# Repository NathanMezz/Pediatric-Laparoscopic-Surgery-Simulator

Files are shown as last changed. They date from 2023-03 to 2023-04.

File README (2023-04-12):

Repository for SYSC4907 Capstone Engineering Project "Pediatric Laparoscopic Surgery Simulator" at Carleton University (Fall 2022/Winter 2023)

Group Members:
Nathan Mezzomo
Miles Sutherland (Kilometers4444)
Titus Priscu

Main.py is the main program for running the project.

HSV.py is a supplmentary program from https://toptechboy.com/tracking-an-object-based-on-color-in-opencv/ which allows a user to
find an appropriate range of HSV values for specific colour detection. Modified to find pixel coordinates of centroids of objects.
Can be used for finding HSV ranges needed for ring task in Main.py.

Two Camera HSV.py is a modified version of HSV.py that implements the same functionality as HSV.py, but with two cameras to allow
for 3D object tracking. Attempting to combine two sets of 2D coordinates into one 3D coordinate set.

sensor_data.txt is where all the sensor data from the previous attempt is saved.
outpy.avi is the video recording of the previous attempt.
Warning_list.txt is the list of all warnings and their timestamps from the previous attempt.

Recommended Software:
- Anaconda (For python 3.9 install and libraries)
- PyCharm Community (python IDE)
- Arduino IDE

- The MPU6050's interfacing code was based on the Arduino library "MPU6050_tockn": https://github.com/tockn/MPU6050_tockn noteable changes were with respect to the addressing since using a second MPU6050 requires the change in address "0x68" to "0x69" when using the AD0 pin.  
- The PMW3389's interfacing code was based on the Arduino library "pmw3389_bluemicro": https://github.com/tomKPZ/pmw3389_bluemicro/tree/main/PMW3389 noteable changes was changing the hardcoded CPI from 800 to 16000 to get maximmum precision from the sensor. 

Hardware Setup:
- When fully extracting or inserting graspers from trocars/sensor housings ENSURE to unscrew the optical sensors from the sensor housing. If not done the lens on the sensor can get jammed into the sensor itself by the tool tip. Lens is snug to the shaft to mimic sitting on a flat surface.    
- Both MPU6050 and PMW3389 are bolted into the sensor house and panels respectively using M2 screws. An M2 Allen key can be used to unbolt and bolt the sensors snuggly into their respective locations. 

Setup Instructions:
- Clone repository to desired location.
- Install Anaconda (Automatically installs python).
- Install PyCharm Community.
- Install Arduino IDE.
- In the Sensor_Code -> Complete_Sensor_Code directory, copy MPU6050_1, MPU6050_2, and PMW3389 folders into Arduino Libraries folder. This is typically found in the user's Documents -> Arduino -> Libraries.
- Open Anaconda Powershell, and install the OpenCV2 python library by using "pip install opencv-python".
- Open PyCharm and open the repository as an existing project folder. Choose a Python Interpreter by going to: File -> Settings -> Project -> Python Interpreter. Add A new interpreter and choose Virtualenv Envrionment, and ensure the base interpreter is set as anaconda3\python.exe. This is found in the User's directory by default.
- All other python libraries used in the project can be installed directly in PyCharm by hovering over the errors (caused by missing libraries), and choosing the option to install them, or by going into the Python Interpreter settings and adding a package by searching for it.
- Plug in the camera and Arduino to your computer. Check which COM port the arduino is on through the Arduino IDE. When setting up on a new computer, this port can be different, so it will need to be updated in the start_sensors() function in main.py. The cameraID value in main.py may also need updating, and is typically a value of 0, if it is the only camera on the computer, or 1 if there is already another camera connected (such as a built in laptop camera).
- In Arduino IDE, upload the Complete_Sensor_code.ino code to the arduino, then launch main.py to start the program. The colors for the ring task may need manual calibration, which can be done by updating the HSV ranges (i.e red_low, red_high arrays) with the help of HSV.py.

Video:
https://www.youtube.com/watch?v=Lf4ZpyTEzIQ

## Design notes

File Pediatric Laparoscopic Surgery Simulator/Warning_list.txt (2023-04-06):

Warning Type and times (seconds): 
Force: 
2.96
3.52
4.33
6.68
Left Pitch Acceleration: 
Left Yaw Acceleration: 
Right Pitch Acceleration: 
1.22
Right Yaw Acceleration: 
1.22
Left Surge Acceleration: 
Left Roll Acceleration: 
Right Surge Acceleration: 
1.38
3.62
4.94
6.78
7.08
7.49
7.75
Right Roll Acceleration: 
1.68

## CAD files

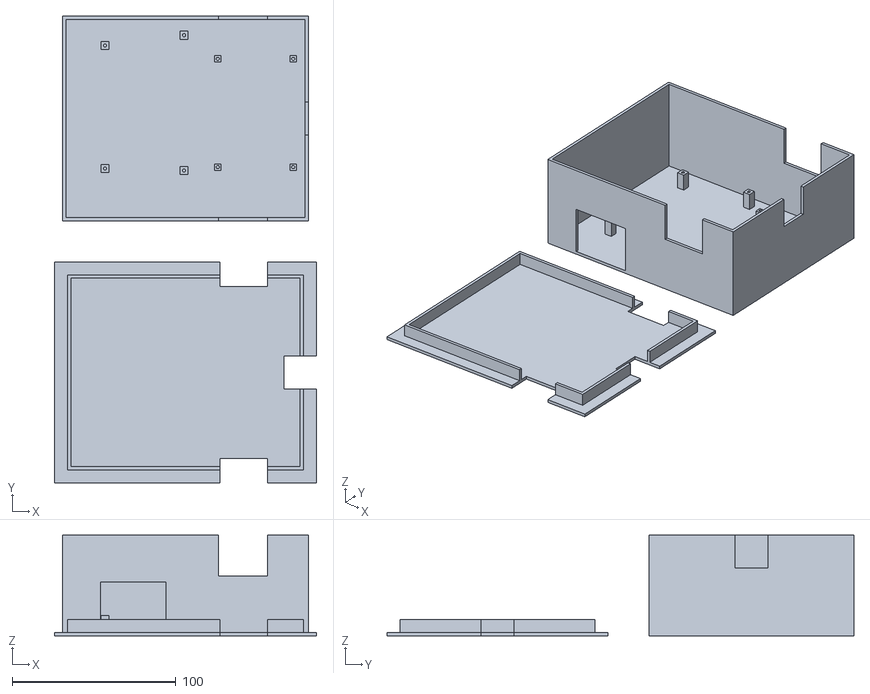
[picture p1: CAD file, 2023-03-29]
Final CAD Files/Capstone_CAD_final/Circuit_Housing.stl
160.0 x 285.0 x 61.5

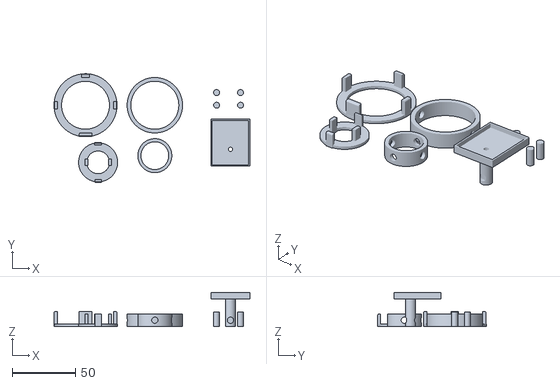
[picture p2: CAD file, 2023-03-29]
Final CAD Files/Capstone_CAD_final/Trocar_Mount v11.stl
155.5 x 86.1 x 27.0

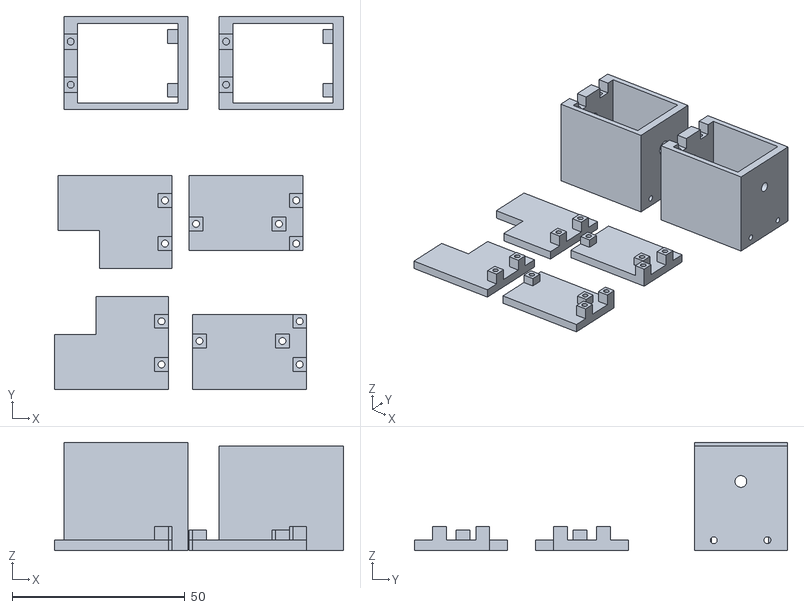
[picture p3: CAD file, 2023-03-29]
Final CAD Files/Capstone_CAD_final/Sensor_Housing.stl
83.7 x 108.0 x 31.3

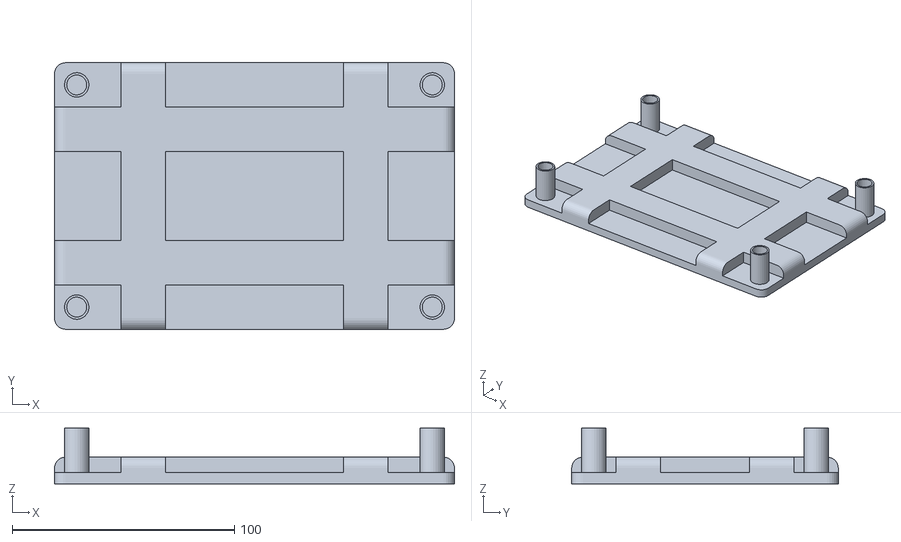
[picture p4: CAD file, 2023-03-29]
Final CAD Files/Capstone_CAD_final/force_plate.stl
180.0 x 120.0 x 25.0

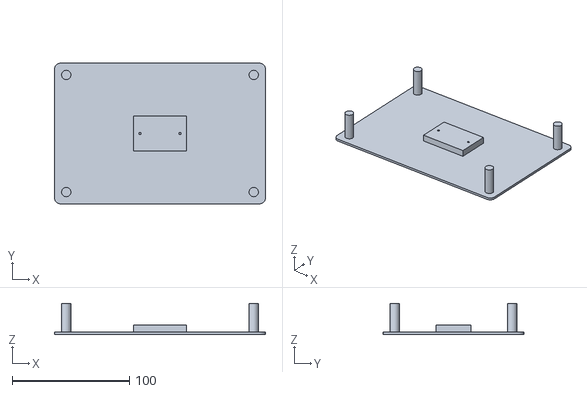
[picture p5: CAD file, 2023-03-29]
Final CAD Files/Capstone_CAD_final/force_base.stl
180.0 x 120.0 x 26.5

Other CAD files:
Schematic/Prototype_To_Arduino.dwg
Schematic/Prototyping Board.dwg
Final CAD Files/Capstone_CAD_final/Circuit_Housing.f3d
Final CAD Files/Capstone_CAD_final/Sensor_Housing.f3z
Final CAD Files/Capstone_CAD_final/Trocar_Mount.f3d
Final CAD Files/Capstone_CAD_final/force_base.f3d
Final CAD Files/Capstone_CAD_final/force_plate.f3d

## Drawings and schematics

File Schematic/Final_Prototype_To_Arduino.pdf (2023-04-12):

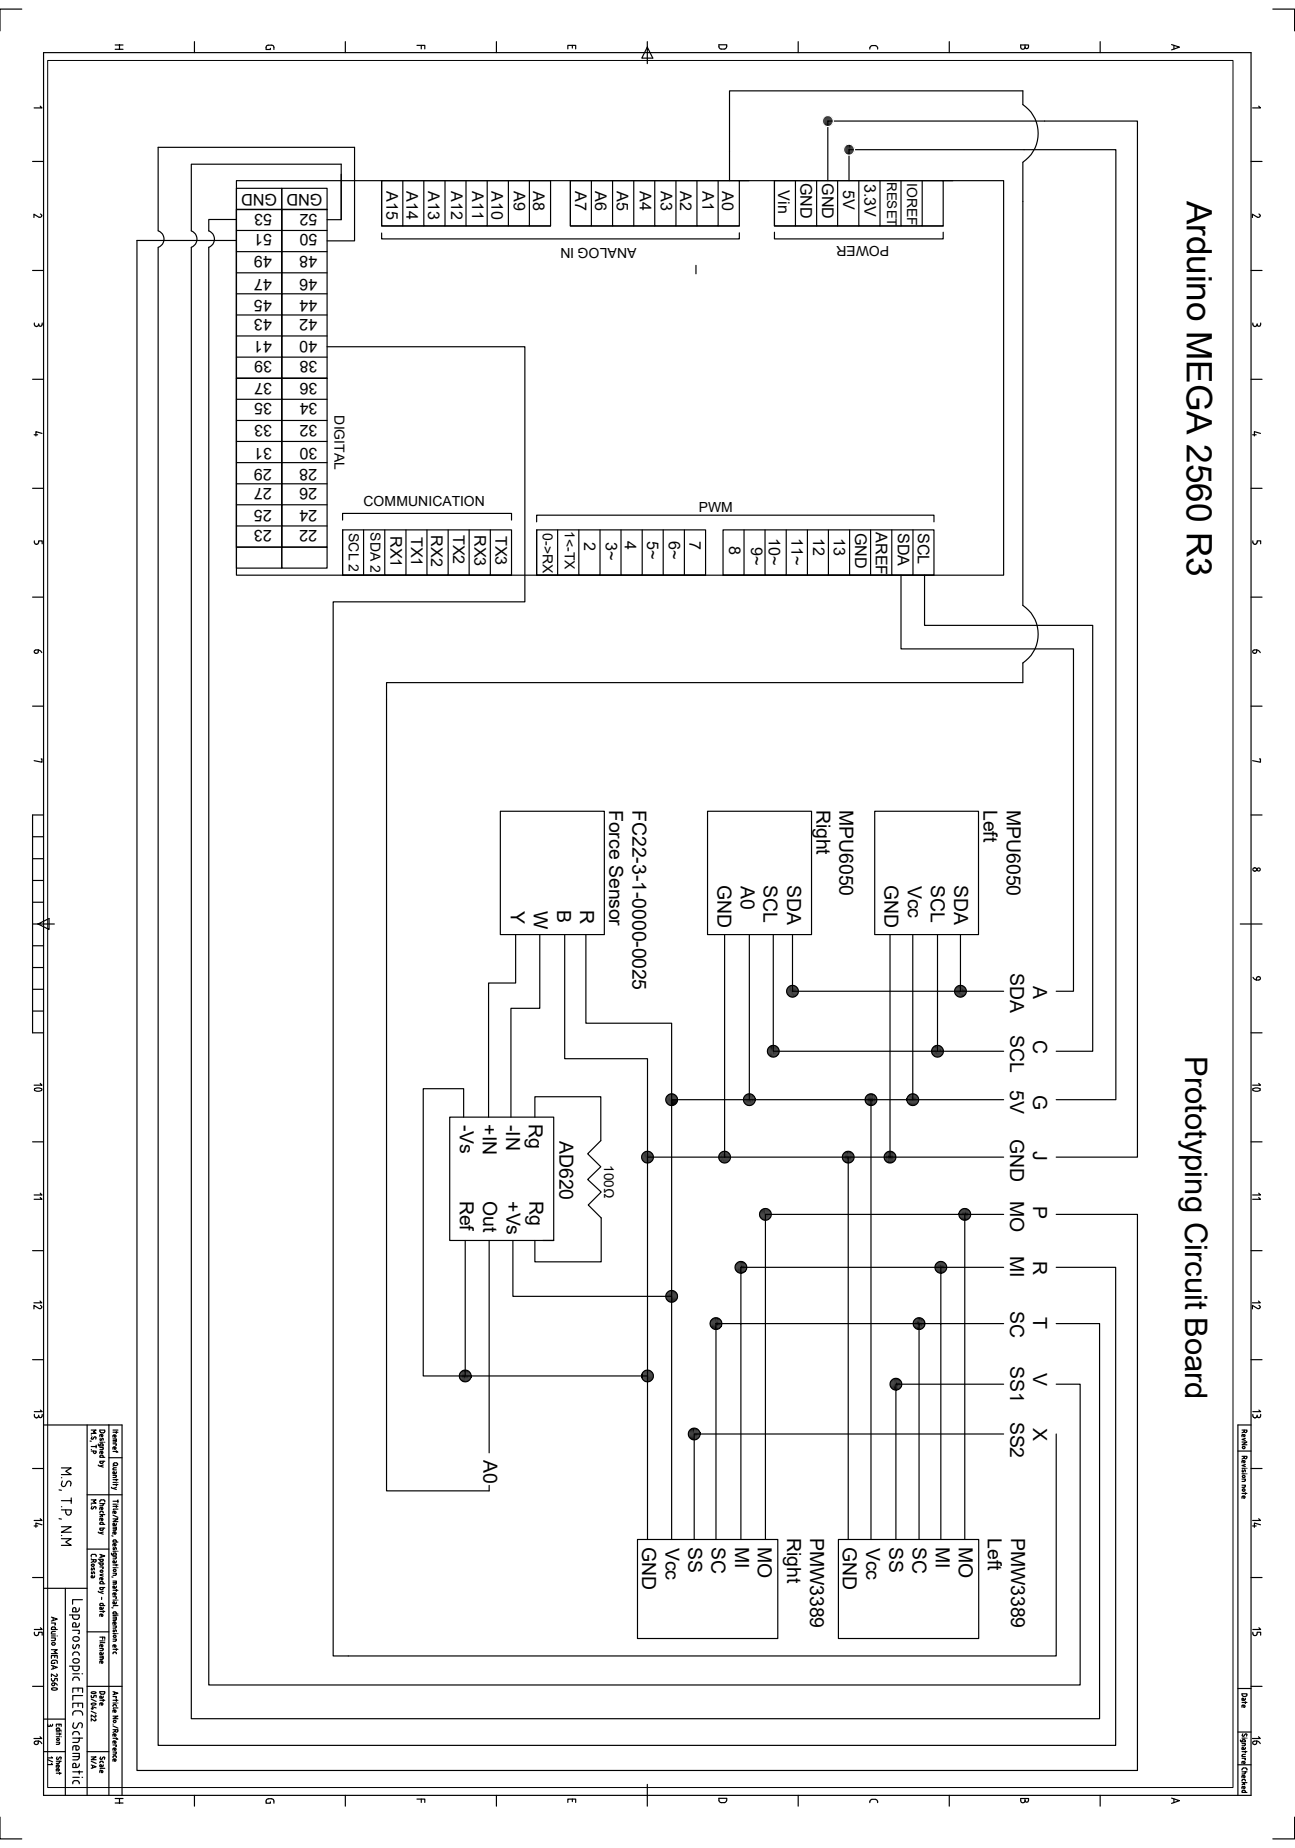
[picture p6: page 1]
GND; COMMUNICATION; PWM; Left MPU6050GND Vcc SCL SDA Right MPU6050GND A0SCL SDA; Left PMW3389 GND Vcc SSSCMI MO Right PMW3389 GND Vcc SSSCMI MO; A C G J P R T V X SDA SCL 5V GND MO MI SC SS1 SS2; Prototyping Circuit Board Force Sensor FC22-3-1-0000-0025 YWBR Ref Out +Vs Rg ⁻Vs +IN⁻INRgAD620

Arduino MEGA 2560 R3 GND AREF SDA SCL 10~ 11~ 121389~ 3.3V RESET IOREF 5V GND GND Vin 23~45~6~70->RX 1<-TX A15 A14 A13 A12 A11 A10 A9A8A7A6A5A4A3A2A1A0

ANALOG IN POWER DIGITAL SCL 2 SDA 2 RX1 TX1 RX2 TX2 RX3 TX3

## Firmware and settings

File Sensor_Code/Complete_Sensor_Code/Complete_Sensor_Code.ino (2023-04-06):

#include <MPU6050_2.h>
#include <MPU6050_1.h>
#include <Wire.h>
#include <PMW3389.h>
#include <SPI.h> 

//Initializing MPU's from libraries 
MPU6050 mpu6050_1(Wire);
MPU60502 mpu6050_2(Wire); //Addressed at 0x69 and 5V on sensor is connected to AD0 

/*
# PIN CONNECTION for PMW3389 with reference to Arduino MEGA 2560 
  * MI = MISO Pin 50 
  * MO = MOSI Pin 51 
  * SS = Slave Select / Chip Select depends on PMW3389 see code below 
  * SC = SPI Clock Pin 52 
  * MT = Motion (active low interrupt line) not necessary in this code 
  * RS = Reset not necessary 
  * GD = Ground 
  * VI = Voltage in up to +5.5V
*/
long timer = millis();

long prevTimeSinceStart = millis();

//Initializing PMW3389's from the library 
PMW3389 sensor1; //uses SS at pin 53 
float x1=0;
float y1=0;  

PMW3389 sensor2; //uses SS at Pin 40 
float x2=0; 
float y2=0; 

float force = 0;

float L_pitch = 0;
float L_yaw = 0;

float R_pitch = 0;
float R_yaw = 0;


float L_PMW_X = 0;
float L_PMW_X_vel = 0;
float L_PMW_X_acc = 0;
float L_PMW_Y = 0;
float L_PMW_Y_vel = 0;
float L_PMW_Y_acc = 0;

float R_PMW_X = 0;
float R_PMW_X_vel = 0;
float R_PMW_X_acc = 0;
float R_PMW_Y = 0;
float R_PMW_Y_vel = 0;
float R_PMW_Y_acc = 0;

float L_yawVel = 0;
float L_yawAcc = 0;
float L_pitchVel = 0;
float L_pitchAcc = 0;
float prev_L_yaw = 0;
float prev_L_yawVel = 0;
float prev_L_pitch = 0;
float prev_L_pitchVel = 0;

float R_yawVel = 0;
float R_yawAcc = 0;
float R_pitchVel = 0;
float R_pitchAcc = 0;
float prev_R_yaw = 0;
float prev_R_yawVel = 0;
float prev_R_pitch = 0;
float prev_R_pitchVel = 0;

float prev_L_PMW_X = 0;
float prev_L_PMW_Y = 0;
float prev_L_PMW_X_vel = 0;
float prev_L_PMW_Y_vel = 0;
float prev_R_PMW_X = 0;
float prev_R_PMW_Y = 0;
float prev_R_PMW_X_vel = 0;
float prev_R_PMW_Y_vel = 0;


void setup() {
  Serial.begin(9600);
//MPU portion 
  Wire.begin();
  mpu6050_1.begin();
  mpu6050_1.calcGyroOffsets(true);
  mpu6050_2.begin(); 
  mpu6050_2.calcGyroOffsets(true); 

   while (!Serial);

  sensor1.begin(53, 16000); // to set CPI (Count per Inch), pass it as the //52 is right ss
  sensor2.begin(40,16000); //40 is left ss

}

void loop() {
  unsigned long currentMillis = millis();
  mpu6050_1.update();
  mpu6050_2.update();
  if (currentMillis - timer > 100) {
  
    unsigned long timeSinceStart = millis();
    //MPU gets data from updates
    float L_yaw = mpu6050_2.getAngleY();
    float L_yawVel = 0;
    float L_yawAcc = 0;
    float L_pitch = mpu6050_2.getAngleX();
    float L_pitchVel = 0;
    float L_pitchAcc = 0;

    float R_yaw = mpu6050_1.getAngleY();
    float R_yawVel = 0;
    float R_yawAcc = 0;
    float R_pitch = mpu6050_1.getAngleX();
    float R_pitchVel = 0;
    float R_pitchAcc = 0;


  /* mpu6050_1.update();
    L_pitch = mpu6050_1.getAngleX();
    L_yaw = mpu6050_1.getAngleY();
    L_accX = mpu6050_1.getAccAngleX();
    L_accY = mpu6050_1.getAccAngleY();*/


    //Left MPU velocity and acceleration
    if (prev_L_yaw != 0) {
        L_yawVel = (L_yaw - prev_L_yaw) * 1000.00 / (timeSinceStart - prevTimeSinceStart); // deg/s
      }
      if (prev_L_pitch != 0) {
        L_pitchVel = (L_pitch - prev_L_pitch) * 1000.00 / (timeSinceStart - prevTimeSinceStart); // deg/s
      }

      // Accelerations
    if (prev_L_yawVel != 0) {
      L_yawAcc = (L_yawVel - prev_L_yawVel) * 1000.00 / (timeSinceStart - prevTimeSinceStart); // deg/s^2
    }
    if (prev_L_pitchVel != 0) {
      L_pitchAcc = (L_pitchVel - prev_L_pitchVel) * 1000.00 / (timeSinceStart - prevTimeSinceStart); // deg/s^2
    }

    //Right MPU velocity and acceleration
    if (prev_R_yaw != 0) {
        R_yawVel = (R_yaw - prev_R_yaw) * 1000.00 / (timeSinceStart - prevTimeSinceStart); // deg/s
      }
      if (prev_R_pitch != 0) {
        R_pitchVel = (R_pitch - prev_R_pitch) * 1000.00 / (timeSinceStart - prevTimeSinceStart); // deg/s
      }

      // Accelerations
    if (prev_R_yawVel != 0) {
      R_yawAcc = (R_yawVel - prev_R_yawVel) * 1000.00 / (timeSinceStart - prevTimeSinceStart); // deg/s^2
    }
    if (prev_R_pitchVel != 0) {
      R_pitchAcc = (R_pitchVel - prev_R_pitchVel) * 1000.00 / (timeSinceStart - prevTimeSinceStart); // deg/s^2
    }

    /*mpu6050_2.update();
    R_pitch = mpu6050_2.getAngleX();
    R_yaw = mpu6050_2.getAngleY();
    R_accX = mpu6050_2.getAccX();
    R_accY = mpu6050_2.getAccY();*/

    //Get data from PMW3389 sensors via readburst
    PMW3389_DATA data1 = sensor2.readBurst();
    PMW3389_DATA data2 = sensor1.readBurst(); 

    if (data1.isMotion || data1.isOnSurface) {
      L_PMW_X=((data1.dx)) + L_PMW_X; // converts to 1mm since 16,000 CPI 16000=32767 in two's compliment so 32767=16,000=inch=25.4mm therefore 1290=1mmm. 

      
      L_PMW_Y=((data1.dy)) + L_PMW_Y;  //Can measure 10cm on ruler and use that bit value to convert

    }
    if (data2.isMotion || data2.isOnSurface) {
      R_PMW_X=((data2.dx)) + R_PMW_X; // converts to 1mm since 16,000 CPI 16000=32767 in two's compliment so 32767=16,000=inch=25.4mm therefore 1290=1mmm. 
      R_PMW_Y=((data2.dy)) + R_PMW_Y;
    }

    

    //Left PMW velocities
    if (prev_L_PMW_X != 0) {
      L_PMW_X_vel = (L_PMW_X- prev_L_PMW_X) / (timeSinceStart - prevTimeSinceStart); // units/s
    }
    if (prev_L_PMW_Y != 0) {
      L_PMW_Y_vel = (L_PMW_Y - prev_L_PMW_Y) / (timeSinceStart - prevTimeSinceStart); // units/s
    }

    //Left PMW accelerations
    if (prev_L_PMW_X_vel != 0) {
      L_PMW_X_acc = (L_PMW_X_vel - prev_L_PMW_X_vel) / (timeSinceStart - prevTimeSinceStart); // units/s^2
    }
    if (prev_L_PMW_Y_vel != 0) {
      L_PMW_Y_acc = (L_PMW_Y_vel - prev_L_PMW_Y_vel) / (timeSinceStart - prevTimeSinceStart); // units/s^2
    }

    //Right PMW velocities
    if (prev_R_PMW_X != 0) {
      R_PMW_X_vel = (R_PMW_X- prev_R_PMW_X) / (timeSinceStart - prevTimeSinceStart); // units/s
    }
    if (prev_R_PMW_Y != 0) {
      R_PMW_Y_vel = (R_PMW_Y - prev_R_PMW_Y) / (timeSinceStart - prevTimeSinceStart); // units/s
    }

    //Right PMW accelerations
    if (prev_R_PMW_X_vel != 0) {
      R_PMW_X_acc = (R_PMW_X_vel - prev_R_PMW_X_vel) / (timeSinceStart - prevTimeSinceStart); // units/s^2
    }
    if (prev_R_PMW_Y_vel != 0) {
      R_PMW_Y_acc = (R_PMW_Y_vel - prev_R_PMW_Y_vel) / (timeSinceStart - prevTimeSinceStart); // units/s^2
    }

    //If not in motion/on surface, reset acceleration value back to zero
    if(!(data1.isMotion || data1.isOnSurface)) {
      L_PMW_X_acc = 0;
      L_PMW_Y_acc = 0;
    }
    if(!(data2.isMotion || data2.isOnSurface)) {
      R_PMW_X_acc = 0;
      R_PMW_Y_acc = 0;
    }



      //Force sensor read at Pin A0 
      force = (analogRead(A0)-136) * 0.011; //136 offset to try to "zero" the value
  
      //Serial.println(String(R_pitch) + " " + String(R_pitchAcc) + "   " + String(R_yawAcc));

      // Division by 1000.00 to convert pitch and yaw to smaller digit value
      Serial.print(String(force) + "|" + String(L_pitchAcc/1000.00) + "|" + String(L_yawAcc/1000.00) + "|" + String(R_pitchAcc/1000.00) + "|" + String(R_yawAcc/1000.00) + "|" + String(L_PMW_Y_acc) + "|"
        + String(L_PMW_X_acc) + "|" + String(R_PMW_Y_acc) + "|" + String(R_PMW_X_acc) + '\n');
      

    //Save previous values
      prevTimeSinceStart = timeSinceStart;
      prev_L_yaw = L_yaw;
      prev_L_yawVel = L_yawVel;
      prev_L_pitch = L_pitch;
      prev_L_pitchVel = L_pitchVel;

      prev_R_yaw = R_yaw;
      prev_R_yawVel = R_yawVel;
      prev_R_pitch = R_pitch;
      prev_R_pitchVel = R_pitchVel;

      prev_L_PMW_X = L_PMW_X;
      prev_L_PMW_X_vel = L_PMW_X_vel;
      prev_L_PMW_Y = L_PMW_Y;
      prev_L_PMW_Y_vel = L_PMW_Y_vel;

      prev_R_PMW_X = R_PMW_X;
      prev_R_PMW_X_vel = R_PMW_X_vel;
      prev_R_PMW_Y = R_PMW_Y;
      prev_R_PMW_Y_vel = R_PMW_Y_vel;


      //Serial.flush();
    //delay(100); 
  }

}

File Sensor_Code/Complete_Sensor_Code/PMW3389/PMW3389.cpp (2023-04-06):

/*
  PMW3366.cpp - Library for interfacing PMW3389 motion sensor module

  Copyright (c) 2019, Sunjun Kim

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
  You should have received a copy of the GNU Lesser General Public
  License along with this library; if not, write to the Free Software
  Foundation, Inc., 51 Franklin St, Fifth Floor, Boston, MA  02110-1301  USA
*/

#include "PMW3389.h"

#define BEGIN_COM                                                              \
  digitalWrite(_ss, LOW);                                                      \
  delayMicroseconds(1)
#define END_COM                                                                \
  delayMicroseconds(1);                                                        \
  digitalWrite(_ss, HIGH)
#define SPI_BEGIN                                                              \
  SPI.beginTransaction(SPISettings(8000000, MSBFIRST, SPI_MODE3))
#define SPI_END SPI.endTransaction()

const unsigned short firmware_length = 4094;
const unsigned char firmware_data[] PROGMEM = {
    0x01, 0xe8, 0xba, 0x26, 0x0b, 0xb2, 0xbe, 0xfe, 0x7e, 0x5f, 0x3c, 0xdb,
    0x15, 0xa8, 0xb3, 0xe4, 0x2b, 0xb5, 0xe8, 0x53, 0x07, 0x6d, 0x3b, 0xd1,
    0x20, 0xc2, 0x06, 0x6f, 0x3d, 0xd9, 0x11, 0xa0, 0xc2, 0xe7, 0x2d, 0xb9,
    0xd1, 0x20, 0xa3, 0xa5, 0xc8, 0xf3, 0x64, 0x4a, 0xf7, 0x4d, 0x18, 0x93,
    0xa4, 0xca, 0xf7, 0x6c, 0x5a, 0x36, 0xee, 0x5e, 0x3e, 0xfe, 0x7e, 0x7e,
    0x5f, 0x1d, 0x99, 0xb0, 0xc3, 0xe5, 0x29, 0xd3, 0x03, 0x65, 0x48, 0x12,
    0x87, 0x6d, 0x58, 0x32, 0xe6, 0x2f, 0xdc, 0x3a, 0xf2, 0x4f, 0xfd, 0x59,
    0x11, 0x81, 0x61, 0x21, 0xc0, 0x02, 0x86, 0x8e, 0x7f, 0x5d, 0x38, 0xf2,
    0x47, 0x0c, 0x7b, 0x55, 0x28, 0xb3, 0xe4, 0x4a, 0x16, 0xab, 0xbf, 0xdd,
    0x38, 0xf2, 0x66, 0x4e, 0xff, 0x5d, 0x19, 0x91, 0xa0, 0xa3, 0xa5, 0xc8,
    0x12, 0xa6, 0xaf, 0xdc, 0x3a, 0xd1, 0x41, 0x60, 0x75, 0x58, 0x24, 0x92,
    0xd4, 0x72, 0x6c, 0xe0, 0x2f, 0xfd, 0x23, 0x8d, 0x1c, 0x5b, 0xb2, 0x97,
    0x36, 0x3d, 0x0b, 0xa2, 0x49, 0xb1, 0x58, 0xf2, 0x1f, 0xc0, 0xcb, 0xf8,
    0x41, 0x4f, 0xcd, 0x1e, 0x6b, 0x39, 0xa7, 0x2b, 0xe9, 0x30, 0x16, 0x83,
    0xd2, 0x0e, 0x47, 0x8f, 0xe3, 0xb1, 0xdf, 0xa2, 0x15, 0xdb, 0x5d, 0x30,
    0xc5, 0x1a, 0xab, 0x31, 0x99, 0xf3, 0xfa, 0xb2, 0x86, 0x69, 0xad, 0x7a,
    0xe8, 0xa7, 0x18, 0x6a, 0xcc, 0xc8, 0x65, 0x23, 0x87, 0xa8, 0x5f, 0xf5,
    0x21, 0x59, 0x75, 0x09, 0x71, 0x45, 0x55, 0x25, 0x4b, 0xda, 0xa1, 0xc3,
    0xf7, 0x41, 0xab, 0x59, 0xd9, 0x74, 0x12, 0x55, 0x5f, 0xbc, 0xaf, 0xd9,
    0xfd, 0xb0, 0x1e, 0xa3, 0x0f, 0xff, 0xde, 0x11, 0x16, 0x6a, 0xae, 0x0e,
    0xe1, 0x5d, 0x3c, 0x10, 0x43, 0x9a, 0xa1, 0x0b, 0x24, 0x8f, 0x0d, 0x7f,
    0x0b, 0x5e, 0x4c, 0x42, 0xa4, 0x84, 0x2c, 0x40, 0xd0, 0x55, 0x39, 0xe6,
    0x4b, 0xf8, 0x9b, 0x2f, 0xdc, 0x28, 0xff, 0xfa, 0xb5, 0x85, 0x19, 0xe5,
    0x28, 0xa1, 0x77, 0xaa, 0x73, 0xf3, 0x03, 0xc7, 0x62, 0xa6, 0x91, 0x18,
    0xc9, 0xb0, 0xcd, 0x05, 0xdc, 0xca, 0x81, 0x26, 0x1a, 0x47, 0x40, 0xda,
    0x36, 0x7d, 0x6a, 0x53, 0xc8, 0x5a, 0x77, 0x5d, 0x19, 0xa4, 0x1b, 0x23,
    0x83, 0xd0, 0xb2, 0xaa, 0x0e, 0xbf, 0x77, 0x4e, 0x3a, 0x3b, 0x59, 0x00,
    0x31, 0x0d, 0x02, 0x1b, 0x88, 0x7a, 0xd4, 0xbd, 0x9d, 0xcc, 0x58, 0x04,
    0x69, 0xf6, 0x3b, 0xca, 0x42, 0xe2, 0xfd, 0xc3, 0x3d, 0x39, 0xc5, 0xd0,
    0x71, 0xe4, 0xc8, 0xb7, 0x3e, 0x3f, 0xc8, 0xe9, 0xca, 0xc9, 0x3f, 0x04,
    0x4e, 0x1b, 0x79, 0xca, 0xa5, 0x61, 0xc2, 0xed, 0x1d, 0xa6, 0xda, 0x5a,
    0xe9, 0x7f, 0x65, 0x8c, 0xbe, 0x12, 0x6e, 0xa4, 0x5b, 0x33, 0x2f, 0x84,
    0x28, 0x9c, 0x1c, 0x88, 0x2d, 0xff, 0x07, 0xbf, 0xa6, 0xd7, 0x5a, 0x88,
    0x86, 0xb0, 0x3f, 0xf6, 0x31, 0x5b, 0x11, 0x6d, 0xf5, 0x58, 0xeb, 0x58,
    0x02, 0x9e, 0xb5, 0x9a, 0xb1, 0xff, 0x25, 0x9d, 0x8b, 0x4f, 0xb6, 0x0a,
    0xf9, 0xea, 0x3e, 0x3f, 0x21, 0x09, 0x65, 0x21, 0x22, 0xfe, 0x3d, 0x4e,
    0x11, 0x5b, 0x9e, 0x5a, 0x59, 0x8b, 0xdd, 0xd8, 0xce, 0xd6, 0xd9, 0x59,
    0xd2, 0x1e, 0xfd, 0xef, 0x0d, 0x1b, 0xd9, 0x61, 0x7f, 0xd7, 0x2d, 0xad,
    0x62, 0x09, 0xe5, 0x22, 0x63, 0xea, 0xc7, 0x31, 0xd9, 0xa1, 0x38, 0x80,
    0x5c, 0xa7, 0x32, 0x82, 0xec, 0x1b, 0xa2, 0x49, 0x5a, 0x06, 0xd2, 0x7c,
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
};

//================================================================================
//	PMW3389 Motion Sensor Module

// bascially do nothing here
PMW3389::PMW3389() {}

// public
/*
begin: initalize variables, prepare the sensor to be init.

# parameter
ss_pin: The arduino pin that is connected to slave select on the module.
CPI: initial CPI. optional.
*/
void PMW3389::begin(unsigned int ss_pin, unsigned int CPI) {
  _ss = ss_pin;
  _inBurst = false;
  pinMode(_ss, OUTPUT);
  digitalWrite(_ss, HIGH);

  SPI.begin();
  // SPI.setDataMode(SPI_MODE3);
  // SPI.setBitOrder(MSBFIRST);

  // hard reset
  SPI_BEGIN;
  END_COM;
  BEGIN_COM;
  END_COM; // ensure that the serial port is reset

  adns_write_reg(REG_Shutdown, 0xb6); // Shutdown first
  SPI_END;
  delay(300);

  SPI_BEGIN;
  BEGIN_COM;
  delayMicroseconds(40);
  END_COM;
  delayMicroseconds(40);

  adns_write_reg(REG_Power_Up_Reset, 0x5a); // force reset
  SPI_END;
  delay(50); // wait for it to reboot

  SPI_BEGIN;
  // read registers 0x02 to 0x06 (and discard the data)
  adns_read_reg(REG_Motion);
  adns_read_reg(REG_Delta_X_L);
  adns_read_reg(REG_Delta_X_H);
  adns_read_reg(REG_Delta_Y_L);
  adns_read_reg(REG_Delta_Y_H);
  // upload the firmware
  adns_upload_firmware();
  // SPI.endTransaction();
  SPI_END;

  delay(10);
  setCPI(CPI);
}

// public
/*
setCPI: set CPI level of the motion sensor.

# parameter
cpi: Count per Inch value
*/
void PMW3389::setCPI(uint16_t cpi) {
  uint16_t cpival = constrain((cpi / 50) - 1, 0, 0x013f);
  SPI_BEGIN;
  adns_write_reg(REG_Resolution_H, (cpival >> 8) & 0xff);
  adns_write_reg(REG_Resolution_L, cpival & 0xff);
  SPI_END;
}

// public
/*
getCPI: get CPI level of the motion sensor.

// public
/*
readBurst: get one frame of motion data.
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

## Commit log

2022-11-30 Create Two Camera HSV.py
    For testing two cameras to find 3d coordinates
2022-11-30 Added 2 camera functionality
2022-11-30 Update Two Camera HSV.py
2022-12-09 Create MPU6050_BothMPU_Working.ino
    Arduino code for both MPU6050's to be implemented on the same Aruiono MEGA 2560, be sure to use SDA and SCL pins.
2022-12-09 dwg and pdf files of schematic
    Schematics for Arduino MEGA 2560 Implementation with motion and force sensors
    [Arduino_MEGA_Drawing_V2.dwg]
2022-12-09 Schematics in dwg and pdf
    Schematic for motion and force sensors of the Laparoscopic trainer
    [Arduino_MEGA_Drawing_V2.dwg]
2022-12-09 Create PMW3389_Testing.ino
    PMW3389 Code, currently prints values when on a surface and stops when off a surface. But prints the same values over and over, still troubleshooting.
2022-12-30 Update main.py
    - Made program startup much quicker.
    - Changed FPS to 15. Video recording only seemed to match proper playback speed when set to 15 fps. Can still maybe try setting live camera feed to 30, but it may not be able to hold that fps/other c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
2023-01-10 Update main.py
    Trying to replay video capture in program itself. Having issue where file gets overwritten/corrupt
    [main.py]
2023-01-11 Fixed video playback + upped to 30 FPS
    [main.py]
2023-02-08 Experimenting with sensor inputs
2023-02-10 Added sensor data gathering to main program file and ring task
2023-02-10 fixed crash at end of ring task
    [main.py]
2023-02-10 Changed sensor startup procedure
2023-02-15 Updated sensor code (Miles)
2023-02-15 Update sensor code
2023-02-15 removed temporary sensor delay
2023-03-01 Updated sensor data format & writing to file
2023-03-03 Added live feedback for force sensor, calculated acc for gyros
2023-03-16 Switched left and right sensors, changed warning text
2023-03-29 Final CAD Files
    Final CAD Files used to print all hardware.
    [Circuit_Housing.f3d, Circuit_Housing.stl, Sensor_Housing.f3z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]
2023-03-31 uploaded sensor libraries
2023-04-06 added timer to suturing task
2023-04-12 Updated Schematics
    Updated Schematics of Prototyping board and prototyping board interface to microcontroller.
    [Arduino_MEGA_Drawing_V2.dwg, Prototype_To_Arduino.dwg, Prototyping Board.dwg]
2023-04-12 Updated README
    Added Hardware set up and Arduino libraries used with major changes to said libraries
